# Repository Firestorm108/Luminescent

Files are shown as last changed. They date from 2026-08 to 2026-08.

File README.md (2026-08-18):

# Luminescent

A 60W handheld portal gun based on industrial surplus I acquired off eBay. I use a very high power laser diode array that is from industrial laser modules for purposes like copper treatment. It has a fully custom board that manages constant current regulation and battery management.
It fits inside a 3D printable portal gun with a voltmeter, safety, and trigger. 

<h1>Laser Safety</h1>

** Make sure to ALWAYS buy laser goggles from a reputable brand and with properly rated specifications. **

** Lasers are extremely dangerous and you should never look at them directly and always wear proper safety goggles. **

** I am not responsible for any damage caused from irresponsibly using lasers. ** 

**General Tips for Working with Lasers:**

* The glasses that come with lasers are NOT safe, and will not protect your eyes.

* Lasers over 5mW require proper laser goggles, 5mW is still dangerous however the blink reflex protects you in most cases.

* Cutting with lasers releases fumes which need to be filtered or ventilated to a window, preferably both.

* An enclosure is the BARE minimum for safety along with properly rated laser goggles.

* Do LOTS of research before working with lasers. Diode lasers need to be treated very carefully especially.

# Pictures







# Bill of Materials

| Item | Price | Link |
| --- | ----: | --- |
| JLCPCB + Assembly + Shipping |  $170 | [JLCPCB](https://jlcpcb.com) |
| Blue Laser Diode Array |  $140 | [eBay](https://www.ebay.com/itm/117338976687) |
| LM338 | $6 | [AliExpress](https://www.aliexpress.us/item/3256809812350367.html) |
| Toggle Switches | $3 | [AliExpress](https://www.aliexpress.us/item/3256805504896607.html) |
| 0.625 ohm Resistors | $2 | [AliExpress](https://www.aliexpress.us/item/3256809808109885.html) |
| Mini Voltmeter | $2 | [AliExpress](https://www.aliexpress.us/item/3256807826514920.html) |
| Lithium Ion Battery + Charger (XT60 - DC) | $32 | [AliExpress](https://www.aliexpress.us/item/3256811403962565.html) |
| Cooling Fans + Heatsink | $12 | [AliExpress](https://www.aliexpress.us/item/2251832856177807.html) |
| Collimating Laser Lenses | $40 | [eBay](https://www.ebay.com/itm/236181151103) |

## Cost Summary

| | Amount |
| --- | ---: |
| **Subtotal** | **$407** |
| **Tax** |  **$43** |
| **Total** | **$450** |

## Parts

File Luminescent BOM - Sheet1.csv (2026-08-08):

Item | Price | Link
JLCPCB + Assembly + Shipping | $170 | jlcpcb.com
Blue Laser Diode Array | $140 | https://www.ebay.com/itm/117338976687
LM338 | $6 | https://www.aliexpress.us/item/3256809812350367.html
Toggle Switches | $3 | https://www.aliexpress.us/item/3256805504896607.html
0.625 ohm Resistors | $2 | https://www.aliexpress.us/item/3256809808109885.html?
Mini Voltmeter | $2 | https://www.aliexpress.us/item/3256807826514920.html
Lithium Ion Battery + Charger (XT60 - DC) | $32 | https://www.aliexpress.us/item/3256811403962565.html
Cooling Fans + Heatsink | $12 | https://www.aliexpress.us/item/2251832856177807.html?
Collimating Laser Lenses | $40 | https://www.ebay.com/itm/236181151103
Price: | $407
Tax: | $43
Total: | $450

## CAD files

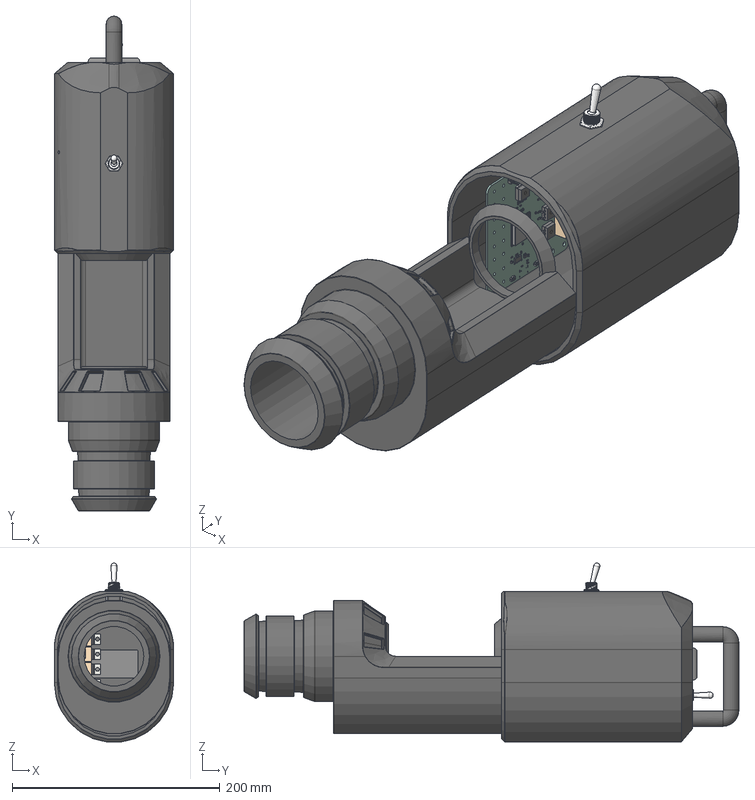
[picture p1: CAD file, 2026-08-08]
Portal Gun.step
115.0 x 476.5 x 172.4 mm

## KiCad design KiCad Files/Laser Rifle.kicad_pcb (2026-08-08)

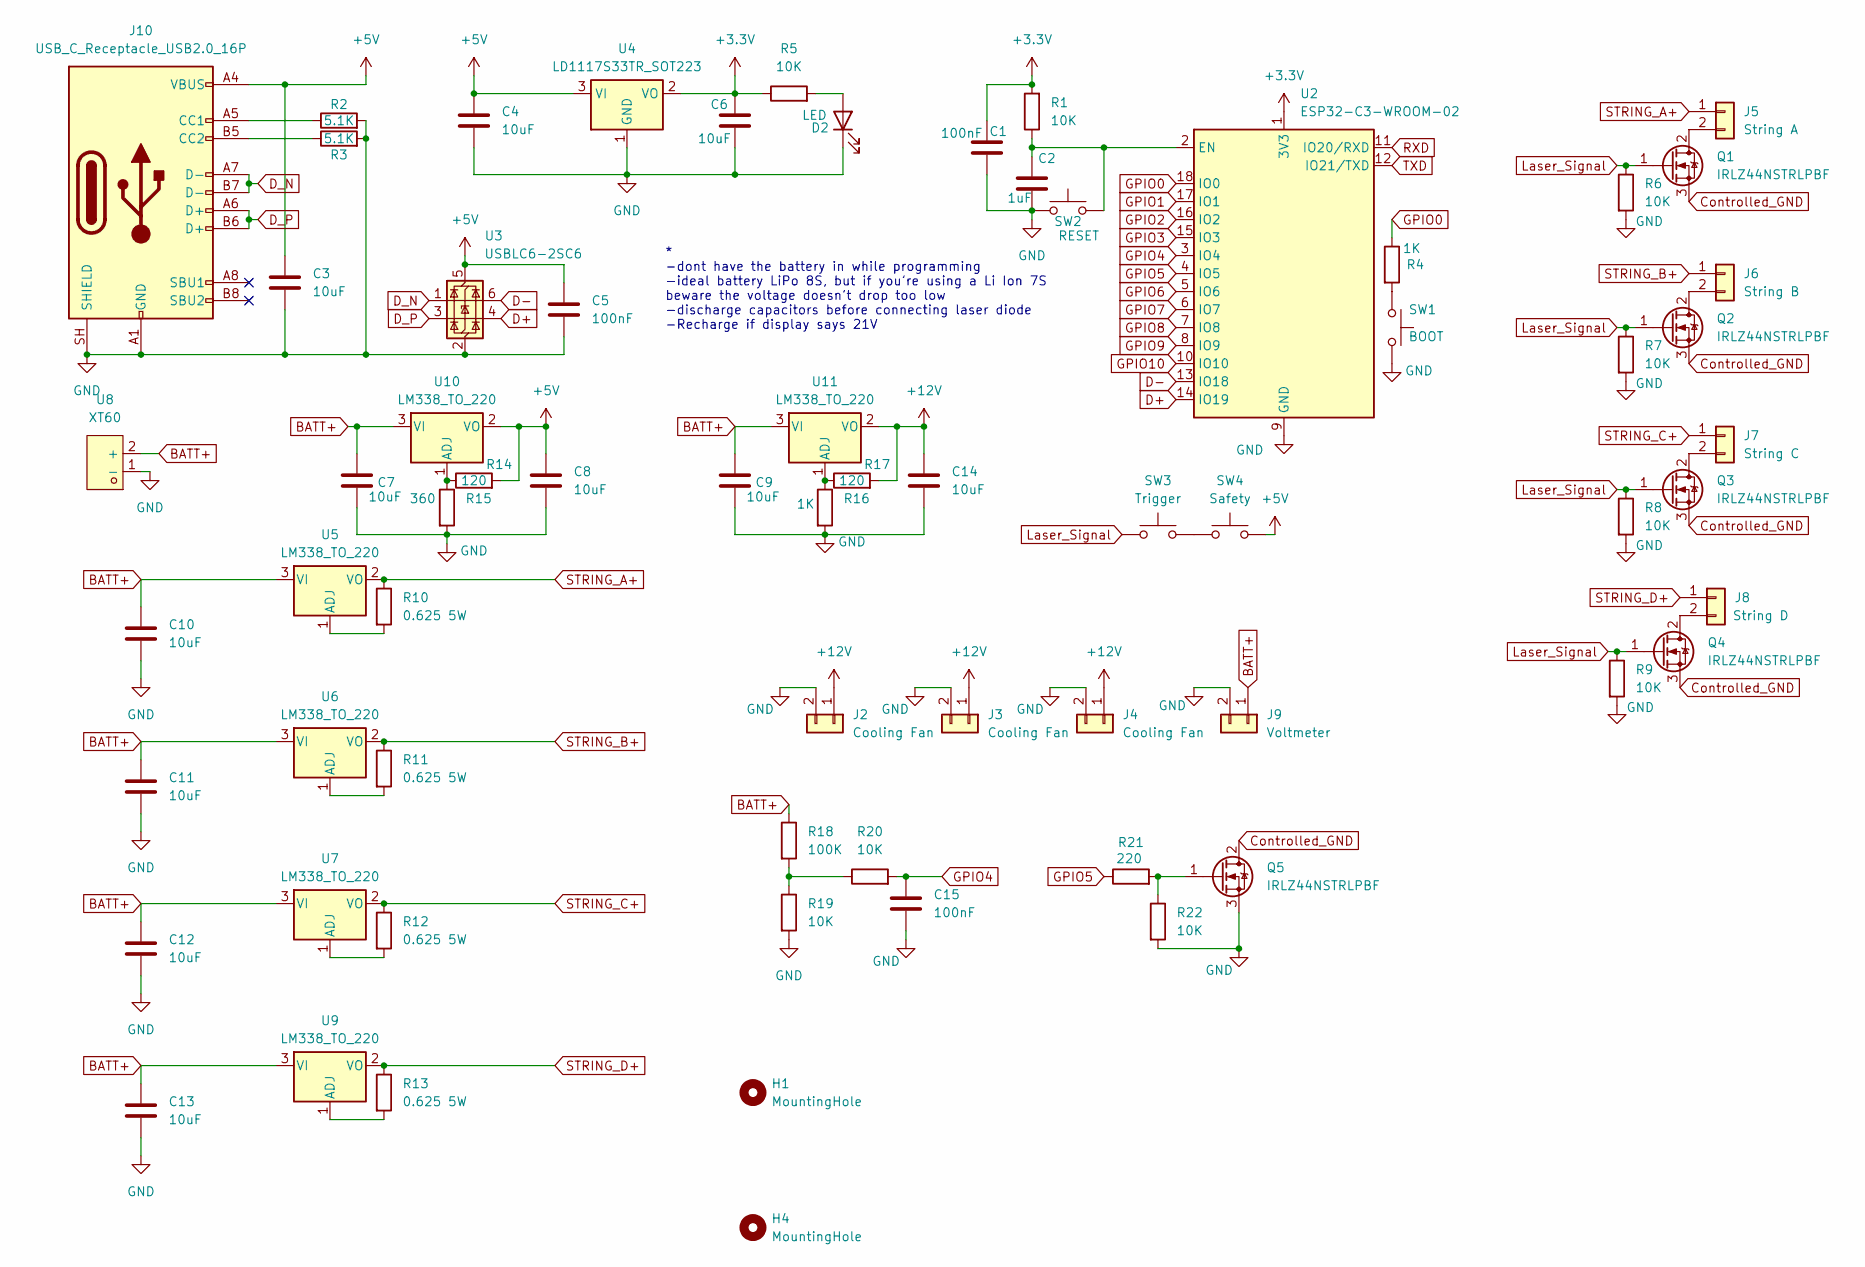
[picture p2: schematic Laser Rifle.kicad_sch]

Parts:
C1, C5, C15: 100nF; C_0603_1608Metric
C2: 1uF; C_0603_1608Metric
C3, C4, C6, C7, C8, C9, C10, C11, C12, C13, C14: 10uF; C_0603_1608Metric
D2: LED; LED_0805_2012Metric
H1, H4: MountingHole; MountingHole_3.2mm_M3
J2, J3, J4: Cooling Fan; PinHeader_1x02_P2.54mm_Vertical
J5: String A; CONN-TH_P10.16_KF135T-10.16-2P
J6: String B; CONN-TH_P10.16_KF135T-10.16-2P
J7: String C; CONN-TH_P10.16_KF135T-10.16-2P
J8: String D; CONN-TH_P10.16_KF135T-10.16-2P
J9: Voltmeter; PinHeader_1x02_P2.54mm_Vertical
J10: USB_C_Receptacle_USB2.0_16P; USB_C_Receptacle_HRO_TYPE-C-31-M-12
Q1, Q2, Q3, Q4, Q5: IRLZ44NSTRLPBF; TO-263-2
R1, R5, R6, R7, R8, R9, R19, R20, R22: 10K; R_0603_1608Metric
R2, R3: 5.1K; R_0603_1608Metric
R4, R16: 1K; R_0603_1608Metric
R10, R11, R12, R13: 0.625 5W; R_Box_L14.0mm_W5.0mm_P9.00mm
R14, R17: 120; R_0603_1608Metric
R15: 360; R_0603_1608Metric
R18: 100K; R_0603_1608Metric
R21: 220; R_0603_1608Metric
SW1: BOOT; SW_Push_SPST_NO_Alps_SKRK
SW2: RESET; SW_Push_SPST_NO_Alps_SKRK
SW3: Trigger; PinHeader_1x02_P2.54mm_Vertical
SW4: Safety; PinHeader_1x02_P2.54mm_Vertical
U2: ESP32-C3-WROOM-02
U3: USBLC6-2SC6; SOT-23-6
U4: LD1117S33TR_SOT223; SOT-223-3_TabPin2
U5, U6, U7, U9, U10, U11: LM338_TO_220; TO-220-3_Vertical
U8: XT60; CONN-TH_XT60; MPN XT60-M.; LCSC Part C98733

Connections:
+3.3V: C1.1, C6.1, R1.2, R5.1, U2.1 (3V3), U4.2 (VO)
+5V: C3.1, C4.1, C5.1, C8.1, J10.A4 (VBUS), J10.A9 (VBUS), J10.B4 (VBUS), J10.B9 (VBUS), R14.2, SW4.2, U3.5 (VBUS), U4.3 (VI), U10.2 (VO)
+12V: C14.1, J2.1, J3.1, J4.1, R17.2, U11.2 (VO)
BATT+: C7.1, C9.1, C10.1, C11.1, C12.1, C13.1, J9.1, R18.1, U5.3 (VI), U6.3 (VI), U7.3 (VI), U8.2 (+), U9.3 (VI), U10.3 (VI), U11.3 (VI)
Controlled_GND: Q1.3 (S), Q2.3 (S), Q3.3 (S), Q4.3 (S), Q5.2 (D)
D+: U2.14 (IO19), U3.4 (I/O2)
D-: U2.13 (IO18), U3.6 (I/O1)
D_N: J10.A7 (D-), J10.B7 (D-), U3.1 (I/O1)
D_P: J10.A6 (D+), J10.B6 (D+), U3.3 (I/O2)
GND: C1.2, C2.2, C3.2, C4.2, C5.2, C6.2, C7.2, C8.2, C9.2, C10.2, C11.2, C12.2, C13.2, C14.2, C15.2, D2.1 (K), J2.2, J3.2, J4.2, J9.2, J10.A1 (GND), J10.A12 (GND), J10.B1 (GND), J10.B12 (GND), J10.SH (SHIELD), Q5.3 (S), R2.2, R3.2, R6.2, R7.2, R8.2, R9.2, R15.2, R16.2, R19.2, R22.2, SW1.2, SW2.1, U2.9 (GND), U2.19 (GND), U3.2 (GND), U4.1 (GND), U8.1 (-)
GPIO0: R4.1, U2.18 (IO0)
GPIO1: U2.17 (IO1)
GPIO2: U2.16 (IO2)
GPIO3: U2.15 (IO3)
GPIO4: C15.1, R20.2, U2.3 (IO4)
GPIO5: R21.1, U2.4 (IO5)
GPIO6: U2.5 (IO6)
GPIO7: U2.6 (IO7)
GPIO8: U2.7 (IO8)
GPIO9: U2.8 (IO9)
GPIO10: U2.10 (IO10)
Laser_Signal: Q1.1 (G), Q2.1 (G), Q3.1 (G), Q4.1 (G), R6.1, R7.1, R8.1, R9.1, SW3.1
unnamed: D2.2 (A), R5.2
unnamed: J5.2, Q1.2 (D)
unnamed: J6.2, Q2.2 (D)
unnamed: J7.2, Q3.2 (D)
unnamed: J8.2, Q4.2 (D)
unnamed: J10.A5 (CC1), R2.1
unnamed: J10.B5 (CC2), R3.1
unnamed: Q5.1 (G), R21.2, R22.1
unnamed: R4.2, SW1.1
unnamed: R18.2, R19.1, R20.1
unnamed: SW3.2, SW4.1
unnamed: C2.1, R1.1, SW2.2, U2.2 (EN)
unnamed: R10.2, U5.1 (ADJ)
unnamed: R11.2, U6.1 (ADJ)
unnamed: R12.2, U7.1 (ADJ)
unnamed: R13.2, U9.1 (ADJ)
unnamed: R14.1, R15.1, U10.1 (ADJ)
unnamed: R16.1, R17.1, U11.1 (ADJ)
RXD: U2.11 (IO20/RXD)
STRING_A+: J5.1, R10.1, U5.2 (VO)
STRING_B+: J6.1, R11.1, U6.2 (VO)
STRING_C+: J7.1, R12.1, U7.2 (VO)
STRING_D+: J8.1, R13.1, U9.2 (VO)
TXD: U2.12 (IO21/TXD)

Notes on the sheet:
* -dont have the battery in while programming -ideal battery LiPo 8S, but if you're using a Li Ion 7S beware the voltage doesn't drop too low -discharge capacitors before connecting laser diode -Recharge if display says 21V

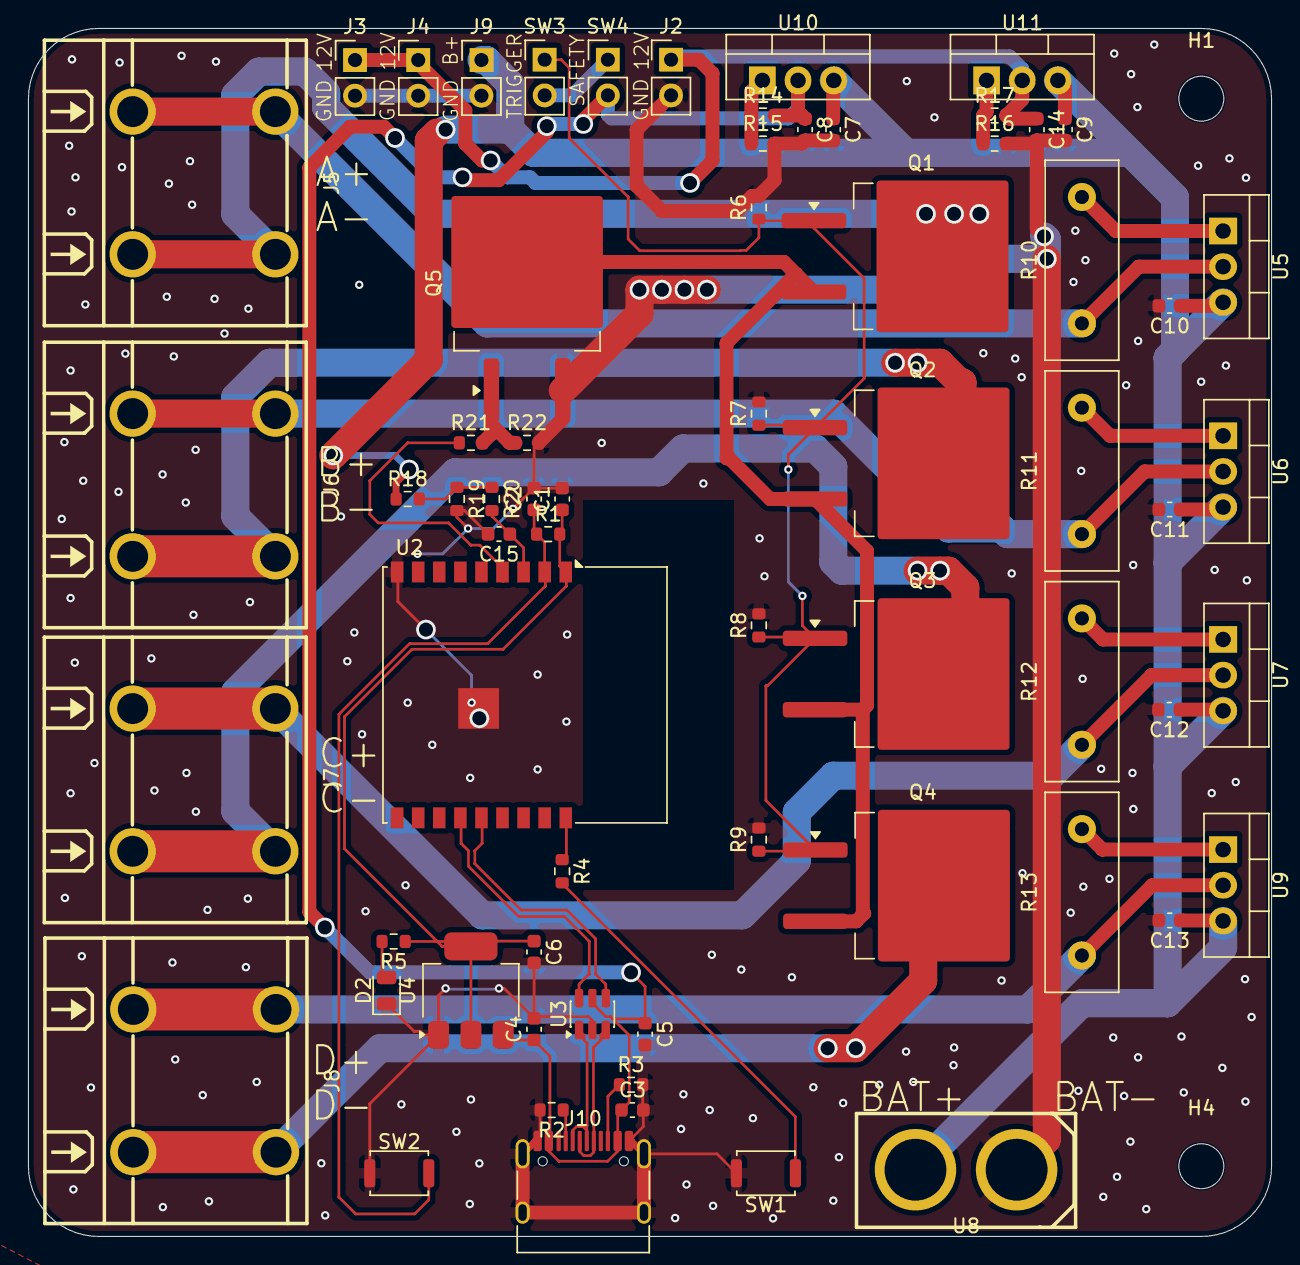
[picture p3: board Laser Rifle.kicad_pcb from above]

Board: 2 copper layers, 88.5 x 86.0 mm, 68 parts (0 on the bottom side), 36 nets.

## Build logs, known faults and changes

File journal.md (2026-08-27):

# August 4th 2026

I started out deciding which laser diode to use.
My two options are NUBB23 and NUBM38. Both diodes are usually either test parts or taken out of old projectors. This means there is not that much documentation on them.
NUBB23 is a lower power 25W diode, much easier to drive and requires less cooling. NUBM38 is much harder to drive, 75W, and requires tons of cooling. I decided to go with the NUBM38 because I was interested in the challenge.
Usually, we drive these diodes with linear voltage regulators rigged to operate in constant current mode. However, this massive diode array is driven at 60V! This is much too high for these linear regulators.
It is possible to run them as two seperate strings at around 30V each, but that is still at the upper limit of these regulators and would most likely generate tons of heat.
I found that Styropyro used the HV9910C IC in his build and looked at the datasheet. Using that, I calculated the components and drew up a schematic of the main laser driver. 

I just finished designing the ESP32, USB, 3.3V reg, and the entire laser driver (which doesn't look like much but since no one on the internet has used this before I had to figure it myself with a datasheet and a calculator). As I was working on designing the BMS, where there will be 4, 4s LiPos in series to get 16S and around 60V, I realized there was a problem with this approach. Well, a few. These batteries are expensive, designing a BMS would make the board massive, etc. etc. etc.

 Screenshot 2026-08-06 at 9 49 22 AM

This is the part where we pivot direction

I just got the CRAZIEST deal on ebay for laser arrays. It's a new model, and literally just solved all my problems. 
I just dropped $140 on this so im PRAYING i can get reimbursed because I'm broke asl now. But basically it has 4 channels instead of 2, and it can take like 22V instead of 60V. 
This means a few things, like I only need one battery. The BMS isn't gonna be insanely massive, I can use a different constant current circuit, less heating, everything! This is amazing.

Time Spent: 5 Hours
# August 5th 2026

Soo the laser arrays don't have lenses on them. Since they're straight from like the factory and not from the NUBARU modules and stuff. So I gotta make my own lens array which might be doable???
Anyways I finished up the schematic. Added tonsss of fun lil features. Like pseudo BMS stuff because I think the ESP32 can handle it lol.

Screenshot 2026-08-06 at 10 12 23 AM

Time Spent: 2 Hours

# August 6th 2026

Woke up bright and early for this. I actually asked gemini what time to wake up and it gave hella good advice.
But I started out by assigning footprints. I also was recording myself doing all of this since I intend to try to turn it into an insta reel.
Screenshot 2026-08-06 at 10 51 36 AM

The layout I decided to go with + mostly power routing
Screenshot 2026-08-06 at 12 17 46 PM

Routing absolutely everything

Screenshot 2026-08-06 at 12 56 36 PM

Screenshot 2026-08-06 at 1 00 48 PM

Overall it looks super good. I'm hoping it works especially since I want other people with similar arrays to be able to use it. It'd be cool to contribute to a niche open source community.

Time Spent: 10 Hours

# August 7th 2026

I thought it'd be super cool to make this into a portal gun. Since you would literally be able to see a massive beam of laser light coming out of it as if it was a real working portal gun.
So I modified a little housing for the PCB, toggle switches for safety and trigger, as well as a voltmeter.

Screenshot 2026-08-07 at 10 01 19 AM
Screenshot 2026-08-07 at 10 01 26 AM

After that I adapted the front part of the inner portal gun to fit in front of the circuit board. The decorative parts of the portal gun aren't in the model, this is just the core. I found this off just some random website, since I'm not that great at artistic modeling, and it wasn't worth redoing it from scratch since it'd perform worse.

Screenshot 2026-08-07 at 10 02 37 AM

There's one last part to do now. Since the arrays I bought don't come with lenses, I have to make my own lens array. The problem is that these arrays have most likely never gotten to the public before until now. They're surplus from a company called NUBARU, and they make extreme high power blue laser industrial machines. I believe I bought it off a dude who worked there. But since these are fresh out of the box from OSRAM, they don't have any lenses on them because they do that in the assembly line where they build their modules. I asked him what lenses they used, and he said a bunch of FACs and SACs. However, I don't know where to buy these. 

Ok, so after looking at the datasheet, I think I found some decent collimating lenses. I talked with some people who know a bit more than optics than me and they said that since each individual laser diode in the array has an output power of less than 4 watts, I don't need a super specialized lens made of some crazy type of glass or something since the power isn't too high relatively. So I did some research and found a good part on ebay that should work.

I hate making BOMs I hate making BOMS I hate making BOMs I hate making BOMS I hate making BOMs I hate making BOMS I hate making BOMs I hate making BOMS I hate making BOMs I hate making BOMS
I hate making BOMs I hate making BOMS I hate making BOMs I hate making BOMS I hate making BOMs I hate making BOMS I hate making BOMs I hate making BOMS I hate making BOMs I hate making BOMS

I made a BOM. On JLCPCB. It sucked but I did it. 

Screenshot 2026-08-08 at 12 15 35 AM
This is for my future reference to see what I need from Aliexpress.
Screenshot 2026-08-08 at 12 17 40 AM

Screenshot 2026-08-08 at 12 23 17 AM

$92, that's not too bad. Time to make ANOTHER freaking bom though.
Time Spent: 5 Hours

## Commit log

2026-08-08 Add journal entries for laser driver project
    Documented the design process and challenges faced while working on a laser driver project, including diode selection, schematic design, and modifications for a portal gun concept. Added images and t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
2026-08-08 Update journal with images and BOM notes
    Added images and notes for future reference on BOM and components.
2026-08-18 Add Bill of Materials and cost summary to README
    Added a Bill of Materials section with item details and cost summary.
